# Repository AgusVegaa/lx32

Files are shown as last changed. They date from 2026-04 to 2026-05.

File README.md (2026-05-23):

<div align="center">
  <strong>PULSAR</strong><br>
  <em>LX32K keyboard processor stack: custom 32-bit core, RTL, golden model, LLVM backend, firmware, and host tools.</em>

  Overview | Firmware | Backend | RTL | Tools
</div>

This is the main source code repository for PULSAR. It contains the processor RTL, validation models, toolchain backend, firmware flow, and host utilities.

## Why PULSAR?

- **Determinism:** Hardware and firmware are designed for predictable timing and stable input scanning.
- **Full-stack control:** Custom ISA extensions, compiler backend, and simulation are all in one place.
- **Validation-first:** RTL, golden model, and tests keep behavior aligned across the stack.

## Quick Start

Run `make setup-backend`, then `make librust`.

## Getting Oriented

Start with `docs/README.md`, then `docs/firmware_guide.md` and `docs/backend.md`.

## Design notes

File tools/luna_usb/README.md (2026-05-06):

# pulsar_hid — LUNA USB HID Gateware

USB High-Speed HID keyboard device using [LUNA](https://github.com/greatscottgadgets/luna) on Amaranth HDL.

## What it provides

- USB 2.0 HS (480 Mbps) enumeration
- EP0: control endpoint (standard chapter-9 requests + HID class)
- EP1 IN: 8-byte keyboard report (interrupt, 125 µs interval)
- EP1 OUT: LED-state output report (NumLock, CapsLock, …)
- `sof_irq`: one-cycle pulse per USB SOF → wire to LX32K interrupt input
- Vendor feature reports (bRequest 0x01/0x02) for per-key config access

## USB identifiers

| Field | Value |
|---|---|
| VID | `0x1209` (pid.codes) |
| PID | `0x4C58` |
| Manufacturer | PULSAR Keyboards |
| Product | PULSAR LX32K |

## Install

```bash
pip install -r requirements.txt
```

## Synthesise

```python
from tools.luna_usb.pulsar_hid import PulsarHIDDevice
from amaranth.back.rtlil import convert

dut = PulsarHIDDevice()
with open("pulsar_hid.il", "w") as f:
    f.write(convert(dut, ports=[dut.report_sink.payload, dut.sof_irq]))
```

Then feed `pulsar_hid.il` into the nextpnr/yosys flow for your FPGA target.

## RTL interface

The companion file `rtl/core/usb_hid_bridge.sv` is the SystemVerilog stub that
the LX32K CPU accesses via MMIO (USB_CTRL_BASE = 0x4000_0200).  On FPGA,
replace the stub with a proper AXI/APB bridge to the LUNA USB core.

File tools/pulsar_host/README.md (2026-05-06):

# pulsar_host — PULSAR LX32K Host Configurator

Python CLI for reading and writing the per-key config block on a connected
PULSAR LX32K keyboard over USB HID vendor feature reports.

## Install

```bash
pip install -r tools/pulsar_host/requirements.txt
```

> **macOS / Linux**: you may need `sudo` or a udev rule for raw HID access.
> **Windows**: install the [hidapi](https://github.com/libusb/hidapi) DLL.

## Usage

```
python -m pulsar_host <command> [args]
```

### Commands

| Command | Description |
|---|---|
| `read-config` | Dump the device config as JSON to stdout |
| `write-config FILE` | Write a JSON config file to the device |
| `set-key KEY ACT RST` | Override actuation/reset thresholds for one key |
| `set-layer LAYER KEY USAGE` | Set a single keymap entry |
| `reset` | Restore factory defaults |

### Examples

```bash
# Dump current config
python -m pulsar_host read-config > my_config.json

# Edit and re-flash
$EDITOR my_config.json
python -m pulsar_host write-config my_config.json

# Lower actuation point on key 0 to 100, reset at 60
python -m pulsar_host set-key 0 100 60

# Map layer 1, key 5 to HID usage 0x29 (Escape)
python -m pulsar_host set-layer 1 5 0x29

# Reset to factory defaults
python -m pulsar_host reset
```

## Config JSON format

```json
{
  "magic":     "0x504c5358",
  "version":   1,
  "actuation": [120, 120, ...],   // 64 × u16
  "reset":     [80,  80,  ...],   // 64 × u16
  "noise":     [20,  20,  ...],   // 64 × u16
  "layer":     [4, 5, 6, ...]     // 256 × u8 (4 layers × 64 keys)
}
```

Default thresholds: actuation=120, reset=80, noise=20 (raw Hall ADC units).

## USB identifiers

| Field | Value |
|---|---|
| VID | `0x1209` (pid.codes) |
| PID | `0x4C58` |
| Vendor report ID | `0x40` |
| Report size | 64 bytes |

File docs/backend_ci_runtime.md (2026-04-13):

# LX32 Backend CI + Runtime Flow

This flow keeps LLVM backend builds in one stable CI environment and lets firmware developers use a lightweight runtime image.

## What CI produces

- Commit-versioned toolchain artifact:
  - `llc`
  - `llvm-mc`
  - `llvm-objcopy`
  - `ld.lld`
  - `lx32-llvm` shared libraries
  - `LX32_BACKEND_COMMIT` marker
- Runtime image in GHCR:
  - `ghcr.io/<owner>/lx32-runtime:<commit-sha>`
  - `ghcr.io/<owner>/lx32-runtime:latest` (for `main`)

Workflow file: `.github/workflows/backend-toolchain.yml`.

## Developer usage (no backend rebuild)

Use the runtime-only compose file:

```bash
docker compose -f docker-compose.runtime.yml pull

docker compose -f docker-compose.runtime.yml run --rm lx32 bash -lc 'cat /usr/local/share/LX32_BACKEND_COMMIT && make test-baremetal-deep'
```

Pin a specific commit-built toolchain image:

```bash
LX32_TOOLCHAIN_TAG=<commit-sha> docker compose -f docker-compose.runtime.yml run --rm lx32 bash -lc 'llc --version | head -n 8'
```

## Backend contributors

Backend contributors can still use the heavyweight local build flow (`Dockerfile`) when needed.

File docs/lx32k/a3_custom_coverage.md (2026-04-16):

# A3 Custom ISA Verification Coverage

## Scope

This document tracks verification coverage for the first custom ISA block in RTL and the Rust golden model:

- `LX.SENSOR`
- `LX.MATRIX`
- `LX.DELTA`
- `LX.CHORD`
- `LX.WAIT`
- `LX.REPORT`

## RTL Testbenches

The following directed testbenches run against `rtl/core/lx32_system.sv`:

- `tb/core/lx32_sensor_tb.sv`
  - Covers `LX.SENSOR`, `LX.MATRIX`, `LX.DELTA` datapath results.
  - Verifies decoded `custom_0` path and write-back values.
- `tb/core/lx32_chord_tb.sv`
  - Covers `LX.CHORD` bitmask match/no-match behavior.
- `tb/core/lx32_wait_tb.sv`
  - Covers `LX.WAIT` issue hold and bounded resume behavior.
- `tb/core/lx32_report_tb.sv`
  - Covers `LX.REPORT` request pointer and DMA ack pulse.

## Golden Model Coverage

Rust test:

- `tools/lx32_validator/tests/test_custom_ops.rs`
  - Cross-checks RTL vs golden behavior for:
    - `SENSOR/DELTA/CHORD`
    - `WAIT` stall and release
    - `REPORT` non-write behavior and PC alignment

## Reproducible Run Commands

```bash
cd /Users/axel/Pulsar
make sim TB=lx32_sensor_tb
make sim TB=lx32_chord_tb
make sim TB=lx32_wait_tb
make sim TB=lx32_report_tb
```

```bash
cd /Users/axel/Pulsar
rm -rf .sim/lx32_lib
mkdir -p .sim/lx32_lib
verilator -Wall -Wno-fatal --cc --Mdir .sim/lx32_lib rtl/arch/*.sv rtl/core/*.sv --top-module lx32_system
cargo test --manifest-path tools/lx32_validator/Cargo.toml --test test_custom_ops -- --nocapture
```

## Current Limits

- `sensor_controller.sv` and `dma_controller.sv` are still stubs (A2 level), so timing/backpressure behavior is simplified.
- `LX.REPORT` busy-stall semantics are not stress-tested yet because DMA busy is hardwired in the stub.
- Full 10M-instruction divergence campaign remains pending for A3 completion gate.

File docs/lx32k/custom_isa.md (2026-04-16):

# LX32K Custom ISA Specification

This document defines the contract for the custom instructions of the LX32K processor, the core of the PULSAR keyboard. These instructions provide low-level, high-performance access to the keyboard's specialized hardware, enabling ultra-low-latency input processing.

## Summary

| Instruction | Opcode | Funct3 | Format | Latency | Description |
|---|---|---|---|---|---|
| `LX.SENSOR` | CUSTOM-0 | `000`  | I-Type | 1 cycle | Reads a single 16-bit sensor value. |
| `LX.MATRIX` | CUSTOM-0 | `001`  | I-Type | 1 cycle | Gets a pointer to the 64-key sensor snapshot. |
| `LX.DELTA`  | CUSTOM-0 | `010`  | I-Type | 1 cycle | Calculates the delta between current/previous frame. |
| `LX.CHORD`  | CUSTOM-0 | `011`  | R-Type | 1 cycle | Checks if a key combination (bitmask) is active.  |
| `LX.WAIT` | CUSTOM-1 | `000`  | I-Type | N cycles| Stalls the pipeline for an exact number of cycles.  |
| `LX.REPORT` | CUSTOM-1 | `001`  | I-Type | 1 cycle | Initiates a DMA transfer of the HID report. |

## Opcode Space

The custom instructions occupy the `CUSTOM-0` and `CUSTOM-1` opcode spaces reserved by the RISC-V ISA.

- **`CUSTOM-0` (`0001011`):** R-Type and I-Type instructions that interface with the sensor subsystem.
- **`CUSTOM-1` (`0101011`):** Instructions for pipeline control and DMA operations.

---

## 1. `LX.SENSOR` — Read Individual Sensor

- **Syntax:** `LX.SENSOR rd, rs1`
- **Description:** Reads the 16-bit value of a single Hall effect sensor and sign-extends it into the destination register `rd`. The sensor index is specified in `rs1`. This provides fine-grained access to a specific key's position.

### Specification

- **Encoding:**
  - **Opcode:** `CUSTOM-0` (`0001011`)
  - **funct3:** `000`
  - **Format:** I-Type
- **Latency:** **1 cycle** (fetch → decode → execute → write-back).
- **Registers:**
  - `rs1` (source): The index of the sensor to be read (0-63).
  - `rd` (destination): The 16-bit sensor value, sign-extended to 32 bits.
- **Behavior under contention:**
  - The `sensor_controller` hardware guarantees that a valid sensor value is always available. It continuously scans and buffers all 64 sensors in the background. This instruction reads from that internal buffer, so it **never stalls**.
- **Behavior (Simulation vs. Hardware):**
  - **Simulation:** The value is provided by a SystemVerilog testbench model that can simulate various conditions like noise, different keypress profiles, and variance.
  - **Hardware:** The value is the real-time digital reading from the dedicated ADC channel (ADS8688) corresponding to the addressed sensor.
- **C-language Built-in:**
  ```c
  #include <stdint.h>
  /**
   * @brief Reads the 16-bit value of the Hall effect sensor at the given index.
   * @param idx The sensor index (0-63).
   * @return The sensor's current value, sign-extended to 32 bits.
   */
  static inline int32_t __builtin_lx_sensor(uint32_t idx);
  ```

---

## 2. `LX.MATRIX` — Get Sensor Snapshot Pointer

- **Syntax:** `LX.MATRIX rd, rs1`
- **Description:** Returns a pointer to the base address of a 128-byte memory block containing the most recent snapshot of all 64 sensor values. This is the most efficient way to process the entire keyboard state at once. The `rs1` register is ignored but is part of the instruction format for consistency.

### Specification

- **Encoding:**
  - **Opcode:** `CUSTOM-0` (`0001011`)
  - **funct3:** `001`
  - **Format:** I-Type.
- **Latency:** **1 cycle**.
- **Registers:**
  - `rs1` (source): Unused.
  - `rd` (destination): The 32-bit memory address of the first element (`sensor[0]`) in the snapshot array.
- **Behavior under contention:**
  - The `sensor_controller` uses a double-buffering mechanism. While one buffer is being filled with new sensor data, the other holds the last stable snapshot. This instruction always points to the stable, complete buffer. It **never stalls**.
- **Behavior (Simulation vs. Hardware):**
  - **Simulation:** Returns a pointer to a memory region within the simulation environment, which is pre-filled by the testbench's sensor model.
  - **Hardware:** Returns the physical BRAM address where the `sensor_controller` has placed the latest complete snapshot of all 64 sensor values.
- **C-language Built-in:**
  ```c
  #include <stdint.h>
  /**
   * @brief Returns a pointer to the 64-entry array of sensor values.
   * @param col Unused. Maintained for instruction format consistency.
   * @return A pointer to the start of the uint16_t sensor_snapshot[64] array.
   */
  static inline uint16_t* __builtin_lx_matrix(uint32_t col);
  ```

---

## 3. `LX.DELTA` — Calculate Frame-to-Frame Delta

- **Syntax:** `LX.DELTA rd, rs1`
- **Description:** Calculates the difference between the current value of the sensor at index `rs1` and its value from the previous frame. The result is a signed 16-bit integer, which represents the key's velocity.

### Specification

- **Encoding:**
  - **Opcode:** `CUSTOM-0` (`0001011`)
  - **funct3:** `010`
  - **Format:** I-Type.
- **Latency:** **1 cycle**.
- **Registers:**
  - `rs1` (source): The index of the sensor (0-63).
  - `rd` (destination): The signed 16-bit delta, sign-extended to 32 bits. A positive value means the key is being pressed down; a negative value means it is being released.
- **Behavior under contention:**
  - The `sensor_controller` internally maintains two full snapshots: `current_frame` and `previous_frame`. This instruction reads from these dedicated hardware registers. It **never stalls**.
- **Behavior (Simulation vs. Hardware):**
  - Identical. The logic (`current[rs1] - previous[rs1]`) is self-contained within the `sensor_controller` in both simulation and hardware.
- **C-language Built-in:**
  ```c
  #include <stdint.h>
  /**
   * @brief Calculates the velocity of a key by subtracting its previous value from its current one.
   * @param key_idx The sensor index (0-63).
   * @return The signed 16-bit delta, representing velocity.
   */
  static inline int32_t __builtin_lx_delta(uint32_t key_idx);
  ```

---

## 4. `LX.CHORD` — Match Key State Bitmask

- **Syntax:** `LX.CHORD rd, rs1`
- **Description:** Compares a 32-bit mask in `rs1` against the current state of the first 32 keys. If every key corresponding to a `1` in the bitmask is currently active (i.e., pressed), `rd` is set to 1. Otherwise, `rd` is 0. This is used for implementing complex shortcuts and layers.

### Specification

- **Encoding:**
  - **Opcode:** `CUSTOM-0` (`0001011`)
  - **funct3:** `011`
  - **Format:** R-Type.
- **Latency:** **1 cycle**.
- **Registers:**
  - `rs1` (source): A 32-bit bitmask where each bit represents a key.
  - `rd` (destination): `1` if the chord matches, `0` otherwise.
- **Behavior under contention:**
  - The active/inactive state of all keys is maintained in a dedicated hardware register that is updated every frame. This instruction reads from that register. It **never stalls**.
- **Behavior (Simulation vs. Hardware):**
  - Identical. The comparison logic is implemented in hardware and behaves the same in simulation.
- **C-language Built-in:**
  ```c
  #include <stdint.h>
  /**
   * @brief Checks if a combination of keys is currently pressed.
   * @param bitmask A 32-bit mask representing the key chord.
   * @return 1 if all keys in the mask are active, 0 otherwise.
   */
  static inline uint32_t __builtin_lx_chord(uint32_t bitmask);
  ```

---

## 5. `LX.WAIT` — Pipeline Suspension

- **Syntax:** `LX.WAIT rs1`
- **Description:** Stalls the processor pipeline by preventing the fetch of new instructions for a precise number of clock cycles, specified by the value in `rs1`. This is useful for fine-grained timing control, such as debouncing or synchronizing with external hardware.

### Specification

- **Encoding:**
  - **Opcode:** `CUSTOM-1` (`0101011`)
  - **funct3:** `000`
  - **Format:** I-Type. The stall count is in `rs1` (bits[19:15]); `rd` and `imm12` are zero.
- **Latency:** **N cycles**, where N is the value in `rs1`.
- **Registers:**
  - `rs1` (source): The number of clock cycles to wait.
  - `rd`: Unused; always zero in the encoding.
- **Behavior under contention:**
  - Not applicable. This instruction directly controls the pipeline.
- **Behavior (Simulation vs. Hardware):**
  - Identical. In both scenarios, the `control_unit` gates the program counter for exactly N cycles.
- **C-language Built-in:**
  ```c
  #include <stdint.h>
  /**
   * @brief Stalls the pipeline for a precise number of cycles.
   * @param cycles The number of clock cycles to wait.
   */
  static inline void __builtin_lx_wait(uint32_t cycles);
  ```

---

## 6. `LX.REPORT` — Initiate HID Report DMA

- **Syntax:** `LX.REPORT rs1`
- **Description:** Initiates a DMA transfer to send an 8-byte HID report to the USB controller. The memory address of the report data is specified in `rs1`. This is a non-blocking instruction from the CPU's perspective.

### Specification

- **Encoding:**
  - **Opcode:** `CUSTOM-1` (`0101011`)
  - **funct3:** `001`
  - **Format:** I-Type.
- **Latency:** **1 cycle** for the CPU. The DMA transfer proceeds in the background.
- **Registers:**
  - `rs1` (source): A pointer to the 8-byte HID report buffer in memory.
- **Behavior under contention:**
  - If the DMA engine is already busy with a previous transfer, this instruction **will stall** the pipeline until the DMA is ready to accept a new command. This is a critical feature to prevent report corruption and ensure data integrity.
- **Behavior (Simulation vs. Hardware):**
  - **Simulation:** A model of the `dma_controller` accepts the command, and a testbench task simulates the transfer delay and completion signal.
  - **Hardware:** The physical `dma_controller` initiates a bus transaction to move the 8-byte report from BRAM to the USB endpoint's dedicated buffer.
- **C-language Built-in:**
  ```c
  #include <stdint.h>
  /**
   * @brief Sends an 8-byte HID report via DMA to the USB controller.
   * @param report_ptr Pointer to the HID report data structure.
   * @note This function is non-blocking unless the DMA is already busy.
   */
  static inline void __builtin_lx_report(void* report_ptr);
  ```

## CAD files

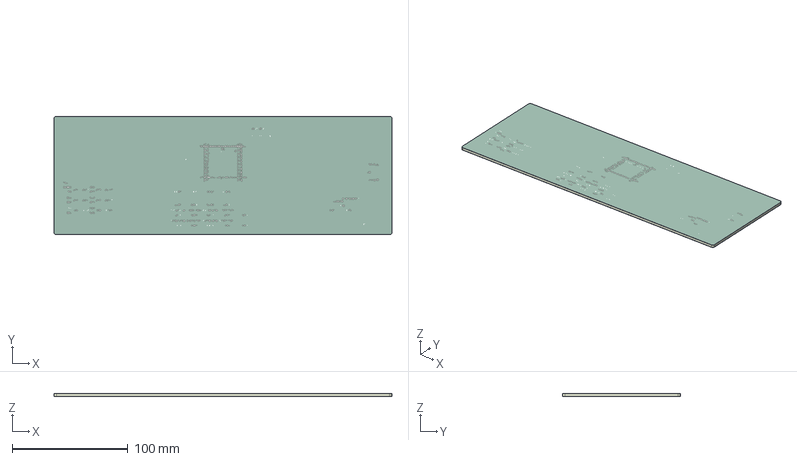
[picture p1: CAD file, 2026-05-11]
cad/pulsar.step
292.0 x 102.0 x 2.62 mm
pulsar _silkscreen x 2
pulsar _soldermask x 2
pulsar _PCB

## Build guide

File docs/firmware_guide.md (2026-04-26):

# PULSAR Firmware Development Guide

Writing and running firmware for the LX32K keyboard processor in C.

---

## Table of Contents

1. [Prerequisites](#1-prerequisites)
2. [Memory model](#2-memory-model)
3. [Custom ISA reference](#3-custom-isa-reference)
4. [C firmware](#4-c-firmware)
5. [Simulate and validate](#5-simulate-and-validate)
6. [Benchmark a program](#6-benchmark-a-program)
7. [Common patterns](#7-common-patterns)

---

## 1. Prerequisites

### Toolchain

| Tool | Purpose | How to get |
|---|---|---|
| LX32 LLVM fork | Compiler, assembler, linker for bare-metal C | `make setup-backend` |
| `ld.lld` | Linker (included in LX32 LLVM) | — |
| `verilator` | RTL simulation for `run-binary` | `brew install verilator` |

### One-time setup

```sh
# Clone + build the LX32 LLVM fork (~15 min on 8 cores).
make setup-backend

# Build the Verilator bridge and Rust validator.
make librust
```

After this, the LX32 toolchain binaries live under `tools/llvm/build/bin/`.
All Makefile targets reference them automatically via `LX32_LLVM_BIN`.

---

## 2. Memory model

The processor uses a flat von Neumann address space. Code and data share the
same 4 KB RAM in the baremetal target.

```
0x0000_0000  ┌─────────────────────────────┐
             │  _start  (5 instructions)   │  crt0.S
0x0000_0014  ├─────────────────────────────┤
             │  .text  (user code)         │
             │  .rodata / .data / .bss     │
             │  stack (grows down)         │
0x0000_0FFF  └─────────────────────────────┘  ← _stack_top (sp = 0x1000)

0x5000_0000  ┌─────────────────────────────┐
             │  Sensor snapshot buffer     │  lx.matrix returns ptr here
             │  (hardware double-buffer)   │
0x5000_007F  └─────────────────────────────┘  64 × u16 = 128 bytes

0xFFFF_F004  ← MMIO exit register (simulator halt)
```

**Key constraint:** 4 KB total (code + stack). A typical firmware binary sits
under 400 bytes; the stack rarely exceeds 128 bytes for scan loops.

---

## 3. Custom ISA reference

Six instructions extend RISC-V for keyboard-specific hardware. All are
1-cycle latency except `lx.wait`.

### CUSTOM-0 — sensor subsystem

| Instruction | Syntax | Operation |
|---|---|---|
| `lx.sensor` | `lx.sensor rd, rs1` | `rd = sign_extend16(sensor[rs1])` |
| `lx.matrix` | `lx.matrix rd, rs1` | `rd = ptr_to_snapshot_buffer` (rs1 ignored) |
| `lx.delta`  | `lx.delta rd, rs1`  | `rd = sensor[rs1] − prev_sensor[rs1]` (velocity) |
| `lx.chord`  | `lx.chord rd, rs1`  | `rd = (active_keys & rs1) == rs1 ? 1 : 0` |

All four are **pure reads** — they never stall, never write memory.

### CUSTOM-1 — pipeline control and DMA

| Instruction | Syntax | Operation |
|---|---|---|
| `lx.wait` | `lx.wait rs1` | freeze PC for N+1 cycles (see note) |
| `lx.report` | `lx.report rs1` | hand `*rs1` (8-byte HID buffer) to DMA engine |

#### `lx.wait` timing — N+1 semantics

`lx.wait N` stalls the pipeline for **N+1 clock cycles**, not N.

| What you write | Effective stall |
|---|---|
| `lx.wait(0)` | 1 cycle (unavoidable decode stall) |
| `lx.wait(1)` | 2 cycles |
| `lx.wait(N)` | N+1 cycles |

**Why:** the RTL counter is loaded with N and counts down to 0; the cycle
where the counter expires is still a frozen cycle because the PC is read
before the clock edge that advances it.

**Practical rule for debounce:** to stall for exactly D cycles, pass `N = D - 1`.

```c
// Wait 50 µs at 50 MHz → 2500 cycles.
// Pass 2499 so effective stall = 2499 + 1 = 2500 cycles.
lx_wait(2499);
```

At debounce timescales the 1-cycle error is 20 ns — irrelevant in practice.
For precise timing in tests, use the formula above.

---

## 4. C firmware

### Project layout

```
my_firmware/
├── main.c
└── (link.ld and crt0.S come from the project baremetal kit)
```

### Intrinsics header

Include `tools/lx32_backend/include/lx32k_intrinsics.h` to access all six
instructions through a typed C API:

```c
#include <stdint.h>
#include "lx32k_intrinsics.h"

// Sensor subsystem
int32_t  lx_sensor(uint32_t idx);          // read sensor idx
uint16_t *lx_matrix(uint32_t col);         // ptr to 64-key snapshot (col=0)
int32_t  lx_delta(uint32_t idx);           // frame-to-frame velocity
uint32_t lx_chord(uint32_t bitmask);       // chord detection

// Pipeline and DMA
void     lx_wait(uint32_t cycles);         // pipeline stall (N+1 semantics)
void     lx_report(const void *report);    // kick DMA → USB endpoint
```

Every wrapper is `__attribute__((always_inline))`, so each call site compiles
to exactly **one machine instruction** regardless of optimization level.

### Minimal program skeleton

```c
#include <stdint.h>
#include "lx32k_intrinsics.h"

int main(void) {
    // The scan loop.  crt0 sets up sp and calls main(); never returns.
    for (;;) {
        uint16_t *snap = lx_matrix(0);     // one cycle

        int32_t best_delta = 0;
        uint32_t best_key  = 64;           // sentinel

        for (uint32_t i = 0; i < 64; i++) {
            int32_t d = lx_delta(i);       // one cycle
            if (d > best_delta) { best_delta = d; best_key = i; }
        }

        if (best_key == 64) continue;      // no key pressed

        lx_wait(2499);                     // 2500-cycle debounce (50 µs @ 50 MHz)

        if (lx_delta(best_key) <= 0) continue; // bounced off

        uint8_t report[8] = {
            0x01, 0x00, 0x00,
            0x04 + (best_key % 26),        // HID usage A=0x04 … Z=0x1D
            0x00, 0x00, 0x00, 0x00
        };
        lx_report(report);                 // one cycle, async DMA
    }
    return 0; // unreachable; silences -Wreturn-type
}
```

### Compile a single file

```sh
make compile-c PROG=my_firmware/main.c
```

This produces `main.elf` and `main.bin` next to the source file.

**What happens internally:**
1. `clang --target=lx32 -O1 -ffreestanding -nostdlib` → `main.bc` → `main.o`
2. `llvm-mc -arch=lx32` assembles `crt0.S` → `crt0.o`
3. `ld.lld -T link.ld crt0.o main.o` → `main.elf`
4. `llvm-objcopy -O binary` → `main.bin`

### Optimization levels

| Level | Use when |
|---|---|
| `-O0` | Debugging codegen failures; every call maps to an explicit frame |
| `-O1` | Default for firmware — inlines intrinsics, eliminates dead code |
| `-Os` | Size-critical: same as `-O1` but prefers smaller sequences |

Set via `LX32_C_OLEVEL=1 make compile-c PROG=...`.

---

## 5. Simulate and validate

C firmware produces a flat `.bin` file that can be loaded into the RTL
simulator directly.

### Run a binary

```sh
make run-binary BIN=path/to/my_firmware.bin
```

Or the runner directly (more options):

```sh
tools/lx32_validator/target/release/run_program \
  --binary path/to/my_firmware.bin
```

The simulator:
1. Loads the binary at address `0x0000_0000` in 64 KB of flat RAM.
2. Resets the LX32 core (5 clock cycles with `rst=1`).
3. Runs until it detects a store to `0xFFFF_F004` (the MMIO exit port written
   by `crt0.S` after `main` returns) or hits `--max-cycles`.

### Verbose trace (cycle-by-cycle)

```sh
tools/lx32_validator/target/release/run_program \
  --binary my_firmware.bin --verbose 2>/dev/null
```

Output per cycle:
```
Cycle 00037: PC=0x00000094  instr=0x00F007AB
Cycle 00038: PC=0x00000094  instr=0x00F007AB [STALL]
Cycle 00039: PC=0x00000098  instr=0x00072783
```

`[STALL]` marks cycles where the PC did not advance (always `lx.wait`).

### JSON output (machine-readable)

```sh
tools/lx32_validator/target/release/run_program \
  --binary my_firmware.bin --json
```

Outputs a single JSON object with all metrics:

```json
{
  "program": "my_firmware",
  "binary_bytes": 276,
  "static_instructions": 69,
  "status": "exited_mmio",
  "exit_code": 0,
  "cycles_total": 64,
  "instructions_committed": 53,
  "stall_cycles": 11,
  "ipc": 0.828,
  "instruction_mix": {
    "alu": 19, "load": 11, "store": 11,
    "custom": 6, "jump": 4, "upper_imm": 2,
    "branch": 0, "other": 0
  }
}
```

### Differential validation (RTL vs golden model)

```sh
make validate          # run the full test suite
make validate-verbose  # with per-test detail
make validate-long     # extended programs (fibonacci, matrix scan)
```

This runs the Rust golden model and the Verilator RTL in lockstep, comparing
PC and register state after every instruction.

---

## 6. Benchmark a program

The benchmark pipeline compiles every C program in
`tools/lx32_backend/tests/baremetal/programs/`, runs each on the simulator,
and collects results in `bench_results.json`.

```sh
make bench-all          # compile + run + collect
make bench-summary      # print the human-readable table
```

To add your own program to the benchmark:

1. Drop `my_test.c` into `tools/lx32_backend/tests/baremetal/programs/`.
2. Run `make bench-all` — it picks up every `*.c` in that directory.

The summary table looks like:

```
Program                    Status         Bytes  S.Instr  Cycles  D.Instr  Stalls     IPC  Exit
─────────────────────────────────────────────────────────────────────────────────────────────────
01_return42                exited_mmio       28        7       5        5       0  1.0000    42
11_run_custom_intrinsics   exited_mmio      276       69      64       53      11  0.8281     0
```

**Reading the columns:**

| Column | Meaning |
|---|---|
| S.Instr | Static instruction count (`binary_bytes / 4`) |
| D.Instr | Dynamic instructions committed (PC advanced) |
| Stalls | Cycles where PC was frozen (`lx.wait`) |
| IPC | `D.Instr / Cycles` — target is 1.0 for stall-free code |
| Exit | Value written to `0xFFFF_F004` by `main`'s return code |

IPC < 1.0 means the program contains `lx.wait` calls. Everything else should
run at exactly IPC = 1.0 on this single-cycle processor.

---

## 7. Common patterns

### Debounce window

```c
// 50 µs at 50 MHz
lx_wait(2499);  // effective = 2500 cycles
```

### Read and act on a single key

```c
int32_t v = lx_delta(key_index);
if (v > THRESHOLD) { /* pressed */ }
```

### Read the full snapshot at once

```c
// one instruction, pointer into hardware double-buffer
uint16_t *snap = lx_matrix(0);
uint16_t raw = snap[42];         // key 42
```

### Chord detection

```c
// keys 0, 2, 5 all pressed simultaneously?
if (lx_chord(0b00100101)) { /* chord active */ }
```

### Send a HID keyboard report

```c
// one cycle, DMA handles the USB transfer in the background
uint8_t report[8] = {0x01, 0x00, 0x00, hid_usage, 0x00, 0x00, 0x00, 0x00};
lx_report(report);
```

`lx.report` returns in 1 cycle if the DMA engine is idle.
If a previous transfer is still in flight the pipeline stalls until the
engine is ready — no explicit polling required.

### Timing-critical section

```c
// Exact 100-cycle critical section.
// Pass 99 so the effective stall is 99+1 = 100 cycles.
lx_wait(99);
```

---

## Quick-reference card

```
COMPILE C         make compile-c PROG=path/to/main.c
RUN BINARY        make run-binary BIN=path/to/main.bin
BENCHMARK         make bench-all && make bench-summary
VALIDATE RTL      make validate
CYCLE TRACE       run_program --binary bin --verbose
JSON METRICS      run_program --binary bin --json
```

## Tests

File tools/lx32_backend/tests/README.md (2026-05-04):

# LX32 Backend Smoke Tests

This folder contains minimal backend smoke tests for early bring-up.

## Scope

These tests validate the first usable SelectionDAG slice:

- formal argument lowering for fixed-arg integer functions,
- return lowering,
- DAG selector wiring in `LX32TargetMachine`.

It also contains a bare-metal C smoke slice for firmware-focused bring-up.

## Run

```bash
bash /Users/axel/lx32/tools/lx32_backend/tests/run_smoke.sh /path/to/llc
```

If no argument is provided, the script tries:

- `/Users/axel/llvm-project/build/bin/llc`
- `llc` from `PATH`

## Notes

- These are bring-up checks, not full `lit` tests yet.
- They only require `-filetype=asm`.
- If your `llc` binary points at a different LX32 source checkout, failures may
  reflect checkout mismatch rather than this workspace.

## Bare-Metal C smoke

Run:

```bash
bash /Users/axel/lx32/tools/lx32_backend/tests/baremetal/run_baremetal_smoke.sh
```

This validates the freestanding C path (`clang -> llc -march=lx32`) for:

- plain integer arithmetic,
- pointer/MMIO loads and stores,
- direct calls and returns,
- no implicit libcalls.

Current expected status: four PASS smoke cases (`return42`, `pointer_store`,
`call_chain`, `branch_loop`).

The compile helper defaults to `-O0` for backend bring-up stability. Override
with `LX32_C_OLEVEL` when probing optimization-related gaps:

```bash
LX32_C_OLEVEL=1 make test-baremetal
```

Enable extra backend diagnostics (`llc -verify-machineinstrs`) via:

```bash
LX32_BACKEND_DEBUG=1 make test-baremetal
```

## Bare-Metal C deep coverage

Run:

```bash
make test-baremetal-deep
```

This extends smoke coverage with comparison-heavy control flow, pointer walking,
iterative Fibonacci, and recursive Fibonacci stress cases.

## What is still missing for executing C end-to-end

- MC/object emission for a full `-filetype=obj` pipeline is still limited in
  this workspace cut, so a full production link/run flow needs more hardening.

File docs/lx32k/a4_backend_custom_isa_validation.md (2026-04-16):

# A4 Backend Custom ISA Validation

## Scope

This check validates custom builtin lowering in the LX32 LLVM backend for:

- `LX.SENSOR`, `LX.MATRIX`, `LX.DELTA`, `LX.CHORD` (`CUSTOM-0` class)
- `LX.WAIT`, `LX.REPORT` (`CUSTOM-1` class)

using:

- `tools/lx32_backend/tests/09_custom_intrinsics.c`
- `tools/lx32_backend/tests/baremetal/programs/10_matrix_scan.c`
- `tools/lx32_backend/tests/check_custom_intrinsics.sh`

## What Is Verified

- Bare-metal C sources compile through `clang -> llc -march=lx32`.
- Emitted assembly includes expected custom mnemonics:
  - `lx.sensor`, `lx.matrix`, `lx.delta`, `lx.chord`, `lx.wait`, `lx.report`
- TableGen opcode-class mapping is pinned in `LX32InstrInfo.td`:
  - sensor/matrix/delta/chord -> `OPC_CUSTOM_0`
  - wait/report -> `OPC_CUSTOM_1`

## Reproducible Run Commands

```bash
cd /Users/axel/Pulsar
bash tools/lx32_backend/tests/check_custom_intrinsics.sh
```

If `llc` is not available yet, build the backend first:

```bash
cd /Users/axel/Pulsar
make build-backend
bash tools/lx32_backend/tests/check_custom_intrinsics.sh
```

## Notes

- This is backend-lowering coverage (assembly/mapping level), not full ELF execution coverage.
- `check_custom_intrinsics.sh` relies on `compile_baremetal_c.sh` toolchain discovery (`LX32_LLVM_BIN`, `LX32_LLC`, `LX32_CLANG` if needed).

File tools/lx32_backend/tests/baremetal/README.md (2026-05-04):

# Bare-Metal Firmware Tests (LX32)

This folder validates the freestanding firmware path for both C and Rust on the
LX32K keyboard processor.

---

## C Tests (`programs/`)

Validates the minimum C-freestanding slice: integer arithmetic, pointer/MMIO
loads and stores, control flow, calls, and the six custom LX32K instructions.

| Program | Tests | Expected exit |
|---|---|---|
| `01_return42.c` | Minimal entrypoint | 42 |
| `02_pointer_store.c` | Pointer dereference load/store | — |
| `03_call_chain.c` | Direct call sequence and return | — |
| `04_branch_loop.c` | Counted loop with branches | — |
| `05_compare_assign.c` | Comparisons and conditional assigns | — |
| `06_pointer_walk.c` | Pointer indexing and accumulation | — |
| `07_fibonacci_iter.c` | Iterative Fibonacci | — |
| `08_fibonacci_recursive.c` | Recursive Fibonacci + deep stack | — |
| `09_custom_intrinsics.c` | All six LX32K hardware instructions | — |

### Run (C)

```bash
# From the repository root:
make test-baremetal           # smoke — programs 01–04
make test-baremetal-deep      # extended — all programs
```

---

## Rust Firmware Tests (`rust_programs/`)

Parallel Rust `#![no_std]` programs that exercise the same code paths as the C
tests, compiled with the custom LX32 rustc fork.

| Program | Tests | Expected exit |
|---|---|---|
| `01_return42.rs` | Constant return | 42 |
| `02_pointer_store.rs` | Stack array LOAD/STORE | 30 |
| `03_call_chain.rs` | Multi-level function calls | 8 |
| `04_branch_loop.rs` | While-loop accumulator | 45 |
| `05_compare_assign.rs` | Conditional subtraction | 10 |
| `06_pointer_walk.rs` | Iterator over stack array | 15 |
| `07_fibonacci_iter.rs` | Iterative fib(10) | 55 |
| `08_fibonacci_recursive.rs` | Recursive fib(10) — stress stack | 55 |
| `09_custom_intrinsics.rs` | All six LX32K hardware instructions | 0 |
| `10_mul_softcall.rs` | Software multiply (`__mulsi3`) | 42 |
| `11_global_array.rs` | Global addressing / PseudoLA lowering  | 50 |
| `12_bitops_shift.rs` | Shift + bitwise lowering paths | 12 |
| `13_nested_loop.rs` | Nested control-flow loops | 10 |
| `14_classify_fn.rs` | Multi-branch compare chain | 3 |
| `15_multi_args.rs` | Five-argument ABI passing | 31 |
| `16_indirect_call.rs` | Conditional branch selecting call path | 31 |
| `17_volatile_mmio.rs` | Volatile MMIO-style loads/stores | 42 |
| `18_sign_extend.rs` | Signed extension from narrow integers  | 27 |
| `19_reg_pressure.rs` | Register-pressure arithmetic mix | 102 |
| `20_shift_mix.rs` | Combined SHL/SHR/OR/XOR pattern | 34 |
| `21_div_mod_softcall.rs` | Unsigned div/mod compiler_builtins | 12 |

### Prerequisites

Build the Rust compiler and LX32 sysroot once:

```bash
make setup-rust           # clone, build stage1 rustc, prep build-std sources + host std for build scripts
```

This takes 20–40 minutes the first time.  Subsequent runs are incremental.

### Run (Rust)

```bash
make build-rust-firmware-tests   # compile only, no simulation
make test-rust-firmware           # compile + run on RTL simulator
```

### Build the keyboard firmware

```bash
make build-firmware               # builds pulsar_pac keyboard example for LX32
make check-pac                    # type-check pulsar_pac on the host (fast)
```

---

## Shared infrastructure

| File | Purpose |
|---|---|
| `crt0.S` | Baremetal entry point (`_start` → `main`) |
| `link.ld` | Memory map: 4 KB RAM at `0x00000000` |
| `crt0.o` | Assembled `crt0.S` (auto-generated by build scripts) |

---

## Notes

- C programs use `-ffreestanding -fno-builtin -nostdlib`.
- Rust programs use `#![no_std] #![no_main]`; `_start` comes from `crt0.S`.
- Rust test runner validates both exit code and key register invariants (`x0 == 0`, `x10/a0 == expected exit`).
- The `rt` feature of `pulsar_pac` provides its own `_start` (replaces `crt0.S`).
- Both C and Rust programs write their exit code to `0xFFFFF004` (simulator halt).

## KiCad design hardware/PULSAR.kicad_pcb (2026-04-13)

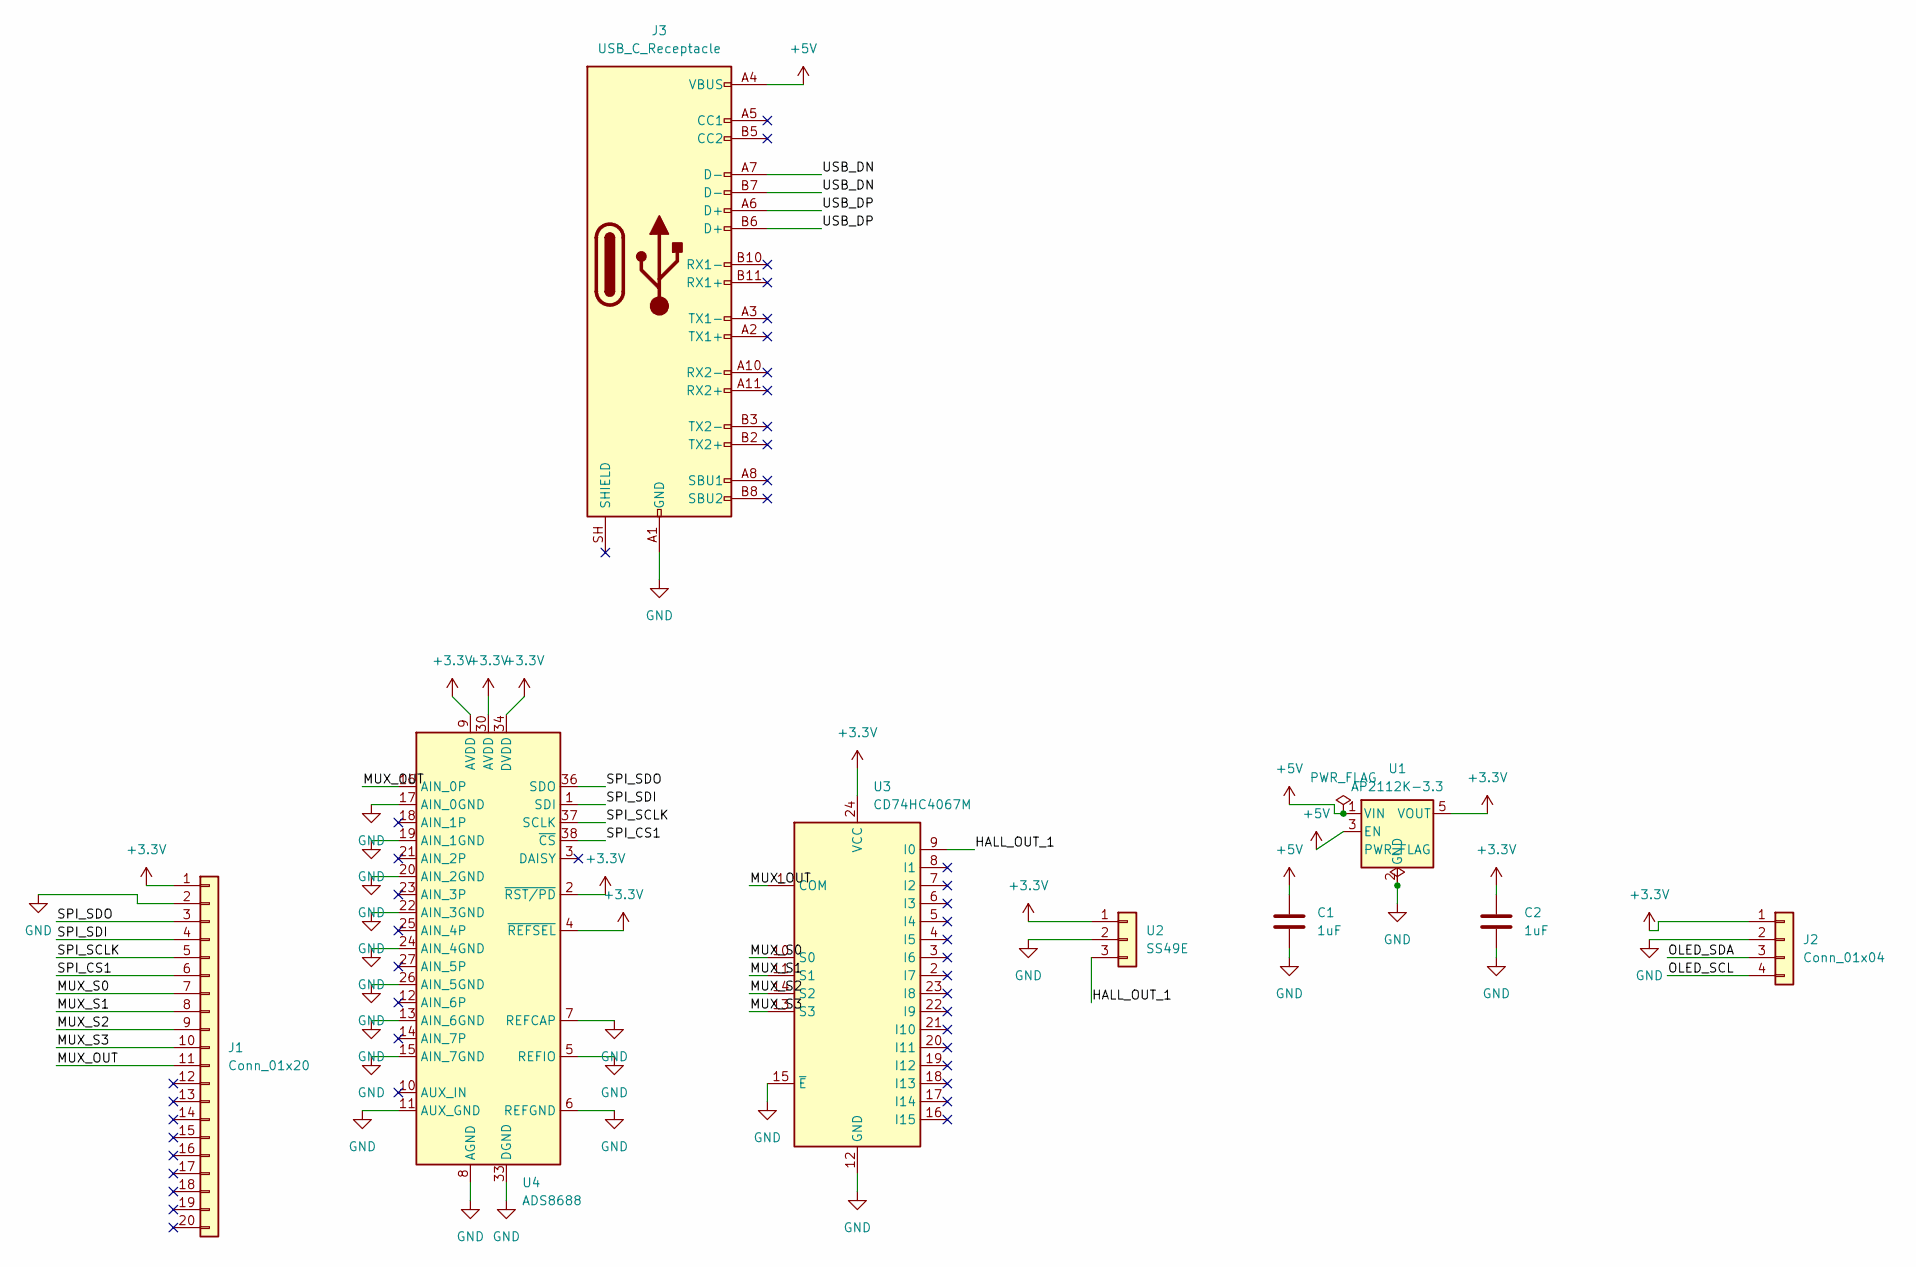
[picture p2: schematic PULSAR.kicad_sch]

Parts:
C1, C2: 1uF; C_0805_2012Metric
J1: Conn_01x20; PinHeader_1x20_P2.54mm_Vertical
J2: Conn_01x04; PinHeader_1x04_P2.54mm_Vertical
J3: USB_C_Receptacle; USB_C_Receptacle_GCT_USB4115-03-C
U1: AP2112K-3.3; SOT-23-5
U2: SS49E; TO-92_Inline
U3: CD74HC4067M; SOIC-24W_7.5x15.4mm_P1.27mm
U4: ADS8688; TSSOP-38_4.4x9.7mm_P0.5mm

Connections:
+3.3V: C2.1, J1.1, J2.1, U1.5 (VOUT), U2.1, U3.24 (VCC), U4.2 (~RST/PD), U4.4 (~REFSEL), U4.9 (AVDD), U4.30 (AVDD), U4.34 (DVDD)
+5V: C1.1, J3.A4 (VBUS), J3.A9 (VBUS), J3.B4 (VBUS), J3.B9 (VBUS), U1.1 (VIN), U1.3 (EN)
/HALL_OUT_1: U2.3, U3.9 (I0)
/MUX_OUT: J1.11, U3.1 (COM), U4.16 (AIN_0P)
/MUX_S0: J1.7, U3.10 (S0)
/MUX_S1: J1.8, U3.11 (S1)
/MUX_S2: J1.9, U3.14 (S2)
/MUX_S3: J1.10, U3.13 (S3)
/OLED_SCL: J2.4
/OLED_SDA: J2.3
/SPI_CS1: J1.6, U4.38 (~CS)
/SPI_SCLK: J1.5, U4.37 (SCLK)
/SPI_SDI: J1.4, U4.1 (SDI)
/SPI_SDO: J1.3, U4.36 (SDO)
/USB_DN: J3.A7 (D-), J3.B7 (D-)
/USB_DP: J3.A6 (D+), J3.B6 (D+)
GND: C1.2, C2.2, J1.2, J2.2, J3.A1 (GND), J3.A12 (GND), J3.B1 (GND), J3.B12 (GND), U1.2 (GND), U2.2, U3.12 (GND), U3.15 (~E), U4.5 (REFIO), U4.6 (REFGND), U4.7 (REFCAP), U4.8 (AGND), U4.11 (AUX_GND), U4.13 (AIN_6GND), U4.15 (AIN_7GND), U4.17 (AIN_0GND), U4.19 (AIN_1GND), U4.20 (AIN_2GND), U4.22 (AIN_3GND), U4.24 (AIN_4GND), U4.26 (AIN_5GND), U4.28 (AGND), U4.29 (AGND), U4.31 (AGND), U4.32 (AGND), U4.33 (DGND)

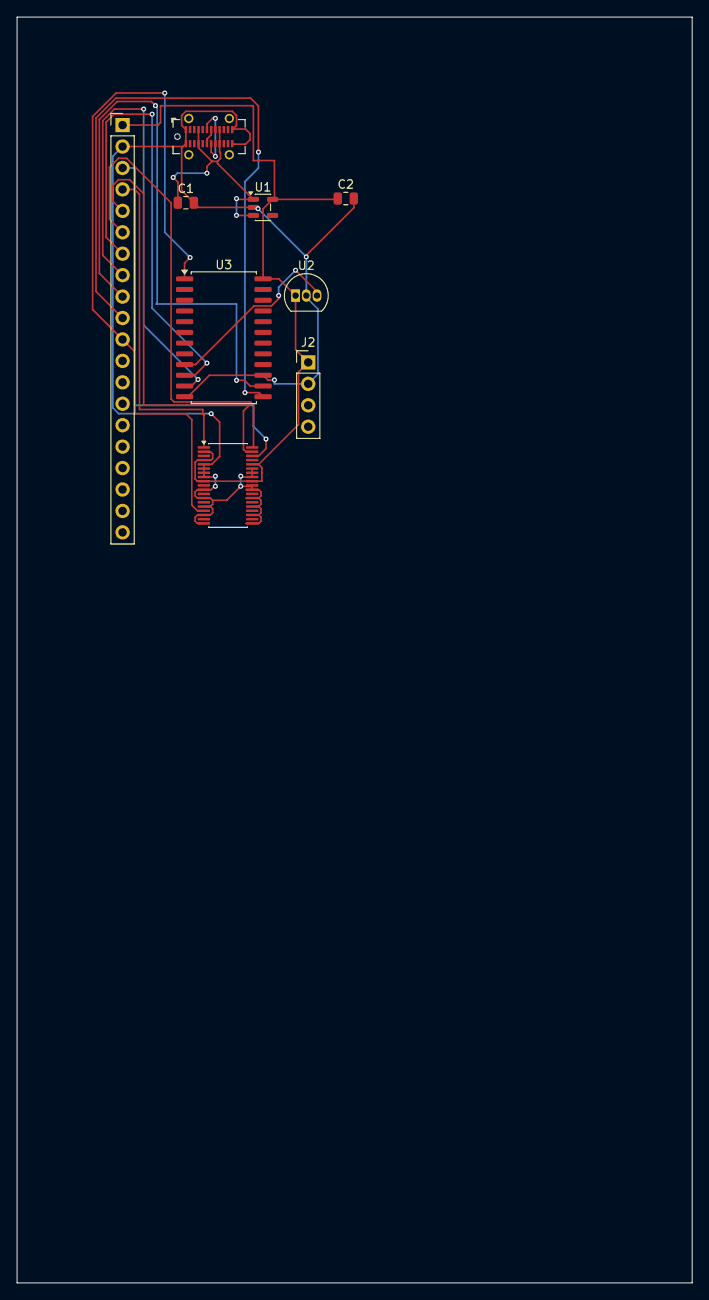
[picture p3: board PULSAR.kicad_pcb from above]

Board: 4 copper layers, 80.0 x 150.0 mm, 9 parts (0 on the bottom side), 15 nets.

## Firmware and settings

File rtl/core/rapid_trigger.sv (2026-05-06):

// rapid_trigger.sv — Hardware rapid-trigger key comparator.
//
// Autonomously scans all 64 sensor keys (one per clock cycle) and fires
// press/release events without any firmware scan loop.
//
// Algorithm per key:
//   Not pressed: track local_min. Fire PRESS  when val - local_min > act_thresh.
//   Pressed:     track local_max. Fire RELEASE when local_max - val > rst_thresh.
//
// An init_done flag gates events until each key has been seen at least once,
// preventing spurious events at power-on.
//
// MMIO register map (base RT_CTRL_BASE = 0x4000_0500):
//   0x00 (R):    event — {valid[31], 23'd0, key[7:2], 1'd0, is_press[0]}
//                        Reading clears the valid bit on the next posedge.
//   0x04 (W):    actuation threshold: {key[23:16], threshold[15:0]}
//   0x08 (W):    reset threshold:     {key[23:16], threshold[15:0]}
//   0x0C (W):    control: bit[0]=1 clears all key state + event
//   0x10 (R):    status: {26'd0, scan_idx[5:0]}

module rapid_trigger (
  input  logic        clk,
  input  logic        rst,

  // Combinatorial read port into the stable sensor frame buffer.
  output logic [5:0]  rt_rd_idx,
  input  logic [15:0] rt_rd_val,

  // Event outputs (mirrored to MMIO word 0).
  output logic        event_valid,
  output logic [5:0]  event_key,
  output logic        event_is_press,

  // MMIO interface
  input  logic        mmio_req,
  input  logic        mmio_we,
  input  logic [5:0]  mmio_addr,
  input  logic [31:0] mmio_wdata,
  output logic [31:0] mmio_rdata
);

  localparam logic [15:0] DEFAULT_ACT = 16'd120;
  localparam logic [15:0] DEFAULT_RST = 16'd80;

  // Per-key state
  logic [15:0] act_thresh [0:63];
  logic [15:0] rst_thresh [0:63];
  logic [15:0] local_min  [0:63];
  logic [15:0] local_max  [0:63];
  logic        pressed     [0:63];
  logic        init_done   [0:63];   // gating flag: true after first sample

  logic [5:0] scan_idx;
  assign rt_rd_idx = scan_idx;

  // Combinatorial signals for the current scan key.
  wire [15:0] s_val  = rt_rd_val;
  wire        s_init = init_done[scan_idx];
  wire        s_pre  = pressed[scan_idx];

  // Extended subtraction detects unsigned underflow via the borrow bit [16].
  wire [16:0] rise_ext = {1'b0, s_val}             - {1'b0, local_min[scan_idx]};
  wire [16:0] fall_ext = {1'b0, local_max[scan_idx]} - {1'b0, s_val};
  wire [15:0] s_rise   = rise_ext[15:0];
  wire [15:0] s_fall   = fall_ext[15:0];
  wire        rise_ok  = !rise_ext[16];
  wire        fall_ok  = !fall_ext[16];

  wire do_press   = s_init && !s_pre && rise_ok && (s_rise > act_thresh[scan_idx]);
  wire do_release = s_init &&  s_pre && fall_ok && (s_fall > rst_thresh[scan_idx]);

  // Reading the event register (word 0) clears event_valid next posedge.
  wire event_rd_ack = mmio_req && !mmio_we && (mmio_addr == 6'h00);

  always_ff @(posedge clk or posedge rst) begin
    if (rst) begin
      scan_idx       <= 6'd0;
      event_valid    <= 1'b0;
      event_key      <= 6'd0;
      event_is_press <= 1'b0;
      for (int i = 0; i < 64; i++) begin
        act_thresh[i] <= DEFAULT_ACT;
        rst_thresh[i] <= DEFAULT_RST;
        local_min[i]  <= 16'h0;
        local_max[i]  <= 16'h0;
        pressed[i]    <= 1'b0;
        init_done[i]  <= 1'b0;
      end
    end else begin
      scan_idx <= scan_idx + 6'd1;

      // First sample: seed both extremes so deltas start from a known state.
      if (!s_init) begin
        local_min[scan_idx] <= s_val;
        local_max[scan_idx] <= s_val;
        init_done[scan_idx] <= 1'b1;
      end else if (!s_pre) begin
        if (s_val < local_min[scan_idx]) local_min[scan_idx] <= s_val;
      end else begin
        if (s_val > local_max[scan_idx]) local_max[scan_idx] <= s_val;
      end

      // Key state transitions.
      if (do_press) begin
        pressed[scan_idx]   <= 1'b1;
        local_max[scan_idx] <= s_val;   // start max tracking from actuation point
      end else if (do_release) begin
        pressed[scan_idx]   <= 1'b0;
        local_min[scan_idx] <= s_val;   // start min tracking from release point
      end

      // Event register: new event wins over read-ack; read-ack wins over idle.
      if (do_press || do_release) begin
        event_valid    <= 1'b1;
        event_key      <= scan_idx;
        event_is_press <= do_press;
      end else if (event_rd_ack) begin
        event_valid <= 1'b0;
      end

      // MMIO write handlers.
      if (mmio_req && mmio_we) begin
        case (mmio_addr)
          6'h01: act_thresh[mmio_wdata[21:16]] <= mmio_wdata[15:0];
          6'h02: rst_thresh[mmio_wdata[21:16]] <= mmio_wdata[15:0];
          6'h03: if (mmio_wdata[0]) begin
            event_valid <= 1'b0;
            for (int i = 0; i < 64; i++) begin
              pressed[i]   <= 1'b0;
              init_done[i] <= 1'b0;
            end
          end
          default: ;
        endcase
      end
    end
  end

  // MMIO read path (combinatorial — no extra latency on event register).
  always_comb begin
    mmio_rdata = 32'h0;
    if (mmio_req && !mmio_we) begin
      case (mmio_addr)
        6'h00:   mmio_rdata = {event_valid, 23'h0, event_key, 1'b0, event_is_press};
        6'h04:   mmio_rdata = {26'h0, scan_idx};
        default: mmio_rdata = 32'h0;
      endcase
    end
  end

// ── Formal / simulation assertions ────────────────────────────────────────────
//
// All assertions are over the CURRENT scan slot (scan_idx).  Because the
// scanner visits each key exactly once per 64 cycles, properties on per-key
// arrays are written in terms of the combinatorial signals that the always_ff
// block uses to update the slot being processed this cycle.
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

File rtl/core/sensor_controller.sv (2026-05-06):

// sensor_controller.sv — Double-frame_buffered Hall-effect sensor interface.
//
// Replaces the earlier stub with a real scanning FSM.
//
// Architecture:
//   - Two complete 64-entry, 16-bit frames (frame_buf[0] and frame_buf[1]).
//   - write_sel selects which frame_buffer the scanner is filling.
//   - The CPU always reads from the "stable" frame_buffer (frame_buf[~write_sel]).
//   - After scanning all 64 sensors the frame_buffers swap atomically and the
//     active_keys bitmask is rebuilt from the completed frame.
//
// ADC model:
//   For simulation, sensor values are generated by a behavioral model.
//   On FPGA, replace the adc_val assignment with SPI ADS8688 read results.
//
// Ports:
//   sensor_idx   — index for LX.SENSOR / LX.DELTA reads (0–63)
//   sensor_val   — current stable value at sensor_idx
//   delta_val    — stable[sensor_idx] − write[sensor_idx]  (velocity proxy)
//   matrix_ptr   — base address of the stable frame_buffer in sensor BRAM
//   chord_mask   — input bitmask for LX.CHORD
//   chord_match  — 1 when (active_keys & chord_mask) == chord_mask
//   snapshot_rdy — 1-cycle pulse each time a new frame completes

module sensor_controller (
    input  logic        clk,
    input  logic        rst,

    // LX32 custom-instruction datapath
    input  logic [5:0]  sensor_idx,
    output logic [15:0] sensor_val,
    output logic [31:0] matrix_ptr,
    output logic [15:0] delta_val,
    input  logic [31:0] chord_mask,
    output logic        chord_match,
    output logic        snapshot_rdy,   // one-cycle pulse per completed frame

    // Rapid-trigger unit direct read port (combinatorial, from stable frame).
    input  logic [5:0]  rt_rd_idx,
    output logic [15:0] rt_rd_val,

    // MMIO configuration / status registers
    input  logic        mmio_req,
    input  logic        mmio_we,
    input  logic [5:0]  mmio_addr,      // word offset (byte_addr[7:2])
    input  logic [31:0] mmio_wdata,
    output logic [31:0] mmio_rdata
);

  import lx32_mmio_pkg::SENSOR_DATA_BASE;
  import lx32_mmio_pkg::SENSOR_BUF_HALF;

  // ── Double-frame_buffered frame storage ─────────────────────────────────────────
  logic [15:0] frame_buf [0:1][0:63];
  logic        write_sel;          // 0 → writing frame_buf[0]; 1 → writing frame_buf[1]

  // Active-key bitmask (first 32 keys; updated at end of each scan frame).
  logic [31:0] active_keys;

  // Configurable press threshold (default 1000 ADC counts).
  logic [15:0] press_threshold;

  // ── Scanner FSM ───────────────────────────────────────────────────────────
  logic [5:0] scan_idx;   // Current sensor being scanned (0–63)

  // Behavioral ADC model for simulation.
  //   Keys 0–7  : simulated pressed  (value = 1200 > default threshold 1000).
  //   Keys 8–63 : simulated idle     (value = 800 + index < 1000).
  // Replace this block with real SPI read results on FPGA.
  logic [15:0] adc_val;
  always_comb
    adc_val = (scan_idx < 6'd8) ? 16'd1200 : (16'd800 + {10'h0, scan_idx});

  always_ff @(posedge clk or posedge rst) begin
    if (rst) begin
      scan_idx        <= 6'd0;
      write_sel       <= 1'b0;
      press_threshold <= 16'd1000;
      active_keys     <= 32'h0000_00FF;
      snapshot_rdy    <= 1'b0;
      for (int i = 0; i < 64; i++) begin
        // Both buffers pre-loaded with the converged ADC model values so that:
        //   sensor_val = adc_val[i]  (deterministic from cycle 0)
        //   delta_val  = 0           (both frames identical → no velocity)
        // This makes the gold model trivially predictable for simulation/fuzzing.
        frame_buf[0][i] <= (i < 8) ? 16'd1200 : (16'd800 + 16'(i));
        frame_buf[1][i] <= (i < 8) ? 16'd1200 : (16'd800 + 16'(i));
      end
    end else begin
      snapshot_rdy <= 1'b0;

      // Write the current ADC sample into the write frame_buffer.
      frame_buf[write_sel][scan_idx] <= adc_val;

      if (scan_idx == 6'd63) begin
        // Frame complete — swap frame_buffers.
        scan_idx     <= 6'd0;
        write_sel    <= ~write_sel;
        snapshot_rdy <= 1'b1;

        // Rebuild active_keys from the frame_buffer we just finished writing.
        // (write_sel hasn't flipped yet at this clock edge.)
        for (int k = 0; k < 32; k++)
          active_keys[k] <= (frame_buf[write_sel][k] > press_threshold);
      end else begin
        scan_idx <= scan_idx + 6'd1;
      end
    end
  end

  // ── CPU read path (combinational, from stable frame_buffer) ─────────────────────
  // The stable frame_buffer is the one NOT currently being written.
  logic rd_sel;
  assign rd_sel = ~write_sel;

  assign sensor_val  = frame_buf[rd_sel][sensor_idx];
  assign rt_rd_val   = frame_buf[rd_sel][rt_rd_idx];
  // delta = stable_value − write_value; positive means key moving toward press.
  assign delta_val   = frame_buf[rd_sel][sensor_idx] - frame_buf[write_sel][sensor_idx];
  // matrix_ptr alternates between the two halves of the sensor data BRAM.
  // write_sel==0 → CPU reads frame_buf[1] → second 32 KiB half.
  // write_sel==1 → CPU reads frame_buf[0] → first  32 KiB half.
  assign matrix_ptr  = write_sel ? SENSOR_DATA_BASE
                                 : (SENSOR_DATA_BASE + SENSOR_BUF_HALF);
  assign chord_match = ((active_keys & chord_mask) == chord_mask);

  // ── MMIO register map ─────────────────────────────────────────────────────
  // Word 0 (0x00): sensor_val for sensor_idx
  // Word 1 (0x04): matrix_ptr
  // Word 2 (0x08): delta_val for sensor_idx
  // Word 3 (0x0C): active_keys[31:0]
  // Word 4 (0x10): press_threshold (R/W)
  // Word 5 (0x14): scan_idx (read-only, for debug)
  always_ff @(posedge clk or posedge rst) begin
    if (rst)
      mmio_rdata <= 32'h0;
    else if (mmio_req) begin
      if (mmio_we) begin
        if (mmio_addr == 6'h04)
          press_threshold <= mmio_wdata[15:0];
      end else begin
        unique case (mmio_addr)
          6'h00: mmio_rdata <= {16'h0, sensor_val};
          6'h01: mmio_rdata <= matrix_ptr;
          6'h02: mmio_rdata <= {16'h0, delta_val};
          6'h03: mmio_rdata <= active_keys;
          6'h04: mmio_rdata <= {16'h0, press_threshold};
          6'h05: mmio_rdata <= {26'h0, scan_idx};
          default: mmio_rdata <= 32'hDEAD_BEEF;
        endcase
      end
    end
  end

endmodule

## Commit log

2026-04-01 Refactor/tablegen patterns pseudos (#73)
    * feat(tablegen): fix pointer regclass mapping and pseudo overrides
    - Added RemapAllTargetPseudoPointerOperands to fix ptr_rc errors.
    - Fixed instruction property inference (mayLoad/mayStore).
    - Organized includes and fixed Pseudo class scope.
    - Added compile_td.sh utility script.
    * fix(tablegen): correct four bugs found in Day 3 review
    SH/SB store patterns used PatFrag wrappers (lx32_sh, lx32_sb) around
    truncstorei16/truncstorei8. PatFrag does not propagate chain or memory
    flags, so the selector could not match them as proper memory ops. Replaced
    with direct truncstorei16/truncstorei8 nodes in the instruction patterns,
    matching the same approach u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
2026-04-01 Feat/llvm backend subtarget stubs (#76)
    * feat: added Subtarget in the script to generate an .inc file
    * feat: add minimal Subtarget and TargetMachine stubs
    - Register Subtarget/TargetMachine sources in LX32CodeGen CMake target
    - Provide minimal buildable LX32Subtarget and LX32TargetMachine skeletons
    - Add placeholder headers for lowering/frame/reg/instr info (stubs)
2026-04-10 feat: add power section schematic AP2112K-3.3 LDO 5V to 3.3V (#4)
    * feat: add power section schematic AP2112K-3.3 LDO 5V to 3.3V
    * feat: add Hall sensor SS49E schematic with HALL_OUT_1 net
    * feat: add MUX CD74HC4067M schematic with control signals
    * feat: add ADS8688 ADC schematic with SPI signals and analog input from MUX
    * feat: add OrangeCrab connector with SPI, MUX and power signals
    * feat: add OLED SSD1306 connector with SPI signals
    [PULSAR.kicad_pcb, PULSAR.kicad_sch]
2026-04-13 CI/runtime split + LX32 backend stabilization (#5)
    * chore: change the clone command with the custom llvm fork
    * refactor: decouple LLVM build, fix TableGen integration and backend paths
    * sync: import backend build + TableGen integration from Pulsar (#88)
    * ci: add backend toolchain artifacts and runtime-only image flow
    * build: add docker build context files required by CI workflow
    * ci: add docker context preflight check before backend image build
    * ci: trigger backend toolchain workflow on sandbox branches
    * build: generate LX32 TableGen .inc files during docker build
    * ci: fix ld.lld artifact extraction (dereference symlink)
    * ci: speed up backend pipeline with nproc, path filt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
2026-04-13 Kicad (#6)
    * feat: add USB-C connector with power and data signals
    * fix: resolve ERC errors, add PWR_FLAG and DAISY no-connect
    * feat: assign footprints to all schematic components
    * feat: setup 4-layer PCB and import schematic footprints
    * feat: initial PCB layout component placement
    * feat: complete PCB routi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
    [PULSAR-B_Cu.gbr, PULSAR-B_Mask.gbr, PULSAR-B_Paste.gbr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]
2026-05-04 Feat/lx32 backend and pac (#17)
    * feat(rust-firmware): add no_std Rust firmware tests and Makefile targets
    Implements bare-metal Rust firmware development for the LX32K keyboard
    processor. Adds 9 #![no_std] test programs that parallel the existing C
    baremetal tests, a cargo workspace, and all Makefile targets for the full
    Rust toolchain lifecycle.
    New Makefile targets:
    check-rust — clone rust-lx32 fork if missing
    build-rust-compiler — build stage1 rustc with LX32 LLVM backend
    build-rust-sysroot — build libcore for lx32-unknown-none-elf
    setup-rust — full toolchain setup (all three above)
    build-firmware — cross-compile keyboard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
2026-05-04 Fix/rust firmware host stdlib and classify (#18)
    build-firmware — cross-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
2026-05-06 Feat/pre hardware tooling (#20)
    * feat: industrialize rust firmware validation
    Expand baremetal Rust firmware coverage with additional ABI/codegen tests and enforce RTL register invariants (x0/x10) in the test runner for production-grade confidence.
    * feat: complete pre-hardware tooling — pipeline, formal, firmware, host
    RTL
    - 2-stage IF|EX pipeline with stall/flush, LX.WAIT counter, DMA stall, debug_stall port
    - sensor_controller: real double-buffer (frame_buf), per-frame snapshot atomicity
    - dma_controller: IDLE→FETCH0→FETCH1→WRITE→DONE FSM with dma_busy signal
    - memory_sim: IRAM 32KiB + DRAM 64KiB split
    - r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
2026-05-06 fix(make): make setup-rust plug-and-play on fresh clones (#21)
    Unshallow rust-lx32 when needed, stop shallow clone for rust fork, and fail fast if stage1 rustc/host stdlib artifacts are missing after x.py.
2026-05-06 fix(make): validate stage1 rustc for lx32 before reuse (#22)
    Treat existing stage1 rustc as valid only if it passes an lx32 target probe. Rebuild automatically when stale/broken and fail if post-build probe still fails, so fresh clones are plug-and-play.
2026-05-06 Fix/bootstrap template parity (#23)
    * fix(make): generate project bootstrap.toml template
    Make ensure-rust-bootstrap emit the same bootstrap structure as the working project template, with host-specific llvm-config path resolved from the local clone.
    * fix(make): set LIBRARY_PATH for stage1 rustc rebuilds
    When build-rust-compiler auto-rebuilds stage1 rustc, pass LIBRARY_PATH=/opt/homebrew/lib so linker finds Homebrew libzstd required by llvm-config libs.
    * fix(pac): static mut warning cleanup
    Use raw-pointer access via addr_of_mut! in keyboard/frame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
2026-05-11 Feat/pcb for pulsar (#24)
    * refactor: initial cleanup to start
    * feat(pcb): power supply schematic complete — U1-U6 buck+LDO rails
    * feat(pcb): FPGA A1 schematic complete — MGT, ADC0-7 pinout, MUX sel
    * feat(pcb): FPGA schematic structure — full pinout A1, hierarchy reorganized
    * feat: added the pcb of the pulsar
    * fix: separation of overlapped components
    [PULSAR-B_Cu.gbr, PULSAR-B_Mask.gbr, PULSAR-B_Paste.gbr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]
2026-05-19 chore: renamed 'pulsar ' to 'pulsar' (#25)
    [adc.kicad_sch, fido2.kicad_sch, fpga.kicad_sch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]
2026-05-20 Feat/config layers (#26)
    * Configurar DRC, layers y tamaños de pista
    * Update pulsar .kicad_prl numeric entries
    Adjust several numeric values in pcb/pulsar/pulsar .kicad_prl (updated entries around the listed numeric array). Also remove the stale temporary KiCad lock file pcb/pulsar/~pulsar .kicad_pcb.lck.
    * feat: let everything to route
    ---------
    [adc.kicad_sch, fido2.kicad_sch, fpga_a1.kicad_sch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]
2026-05-21 refactor: refactored documents and files (#27)
    [LITHOS_Pulsar_Agenda_Proveedores.xlsx, LITHOS_Pulsar_Presupuesto_Fabricacion.xlsx, LITHOS_Pulsar_Presupuesto_Prototipo.xlsx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]
2026-05-23 Refctor/clean up pcb from scratch (#28)
    * refactor: refactored documents and files
    * refactor: I deleted all the pcb and documents from lithos and routing to start from scratch
    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
    [LITHOS_Pulsar_Agenda_Proveedores.xlsx, LITHOS_Pulsar_Presupuesto_Fabricacion.xlsx, LITHOS_Pulsar_Presupuesto_Prototipo.xlsx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]
2026-06-01 create com.kicad (#30)
    In this folder I explain the components that I am going to use in Kicad.
